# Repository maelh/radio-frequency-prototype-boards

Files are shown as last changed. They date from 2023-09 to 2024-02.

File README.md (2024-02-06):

# RF prototyping boards

When designing radio frequency (RF) circuits, we cannot rely on traditional perfboards or breadboards. Suitable boards need a [ground plane](https://en.wikipedia.org/wiki/Ground_plane#Printed_circuit_boards)  (essential for reducing noise in RF circuits), and should have minimal parasitic capacitances and inductances. Breadboards are especially unsuited, due to their RF circuit altering parasitics (mainly created by the horizontal signal rails, and the vertical power rails).

In the same vein, RF protoboards should support SMT components, which have less parasitic inductance compared to their leaded counterparts.

*This repository presents boards suitable for prototyping RF circuits, [ready to be sent](#fabricating-the-rf-proto-boards) to a PCB manufacturer.*

## Original work (ExpressPCB only)

[MegawattKS](https://www.youtube.com/@MegawattKS) gives an accessible [radio design lecture (YouTube)](https://www.youtube.com/watch?v=r_p7AHsSOdw&list=PL9Ox3wpnB0kqekAyz6blg4YdvoEMoJNJY), with [matching slides](https://ecefiles.org/radio-design-101-slides/), and an accompanying guide detailing [how to prototype RF circuits](https://ecefiles.org/rf-circuit-prototyping/).
It's quite a useful course for getting hands on experience and a non-math heavy intuition, using (comparatively) affordable tools, which are introduced as well: [NanoVNA and TinySA for radio design (YouTube)](https://www.youtube.com/watch?v=B7DFOq9rM_M&list=PL9Ox3wpnB0koBGofotI4xS8R0ct0FeYfv).

When you don't happen to have access to the very expensive RF equipment of a university laboratory, this course is ideal, as it was designed to measure and characterize the built RF circuits with the NanoVNA and the TinySA in mind. (Tools which are widely used in DIY/amateur communities, and accordingly have lots of documentation, tutorial videos, and useful addons available online.)

There is also a more advanced university level course ["Designing and Building Transmitters and Receivers"](https://ecefiles.org/rf-circuits-course-notes/) and its [part list](https://ecefiles.org/wp-content/uploads/2023/01/000b_ECE662_PartsList_F19.pdf).

Finally, MegawattKS kindly provided his [original design for ExpressPCB Plus](/original/RFprotoboard_Rev2_17nov22.rrb), which I used to take measurements of the various footprints and layout dimensions.

## Derived work (KiCad, many PCB manufacturers)

I faithfully redesigned the RF protoboard in KiCad, based on those measurements, to enable fabricating them with pretty much any PCB manufacturer.
The manual conversion was necessary, since the original boards are made for ExpressPCB, which uses a format exclusive to this manufacturer, with no export/import options. 

This resulted in two boards (out of the many variations I tried):

- The [standard version](/RF_ProtoBoard), with all the original dimensions and features being kept.

  <div align="center">
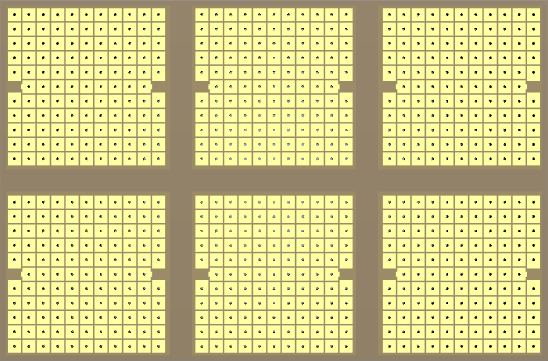
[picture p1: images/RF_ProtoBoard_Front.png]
Front of standard version
    
    <div>Front</div>    
  </div>

  <br/>

  <div align="center">
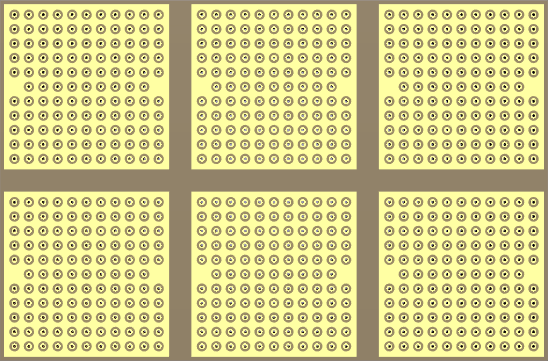
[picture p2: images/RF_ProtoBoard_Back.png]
Back of standard version
    
    <div>Back</div>
  </div>

- The [extended version](/RF_ProtoBoard_Extended), with the following changes compared to the standard version:
  - **added**: mounting holes
  - **added**: screw terminal for power (and pads to solder power wires onto)
  - **extended**: complete 4 pad U.FL connector footprints with silkscreen (for easier alignment)
  - **changed**: ground rings instead of a fully exposed ground plane
    - solder mask only exposes ground rings around the backside of plated through holes; ground rings should form nicer solder joints and hopefully ease solderability to the ground plane

  <br/>
  
  <div align="center">
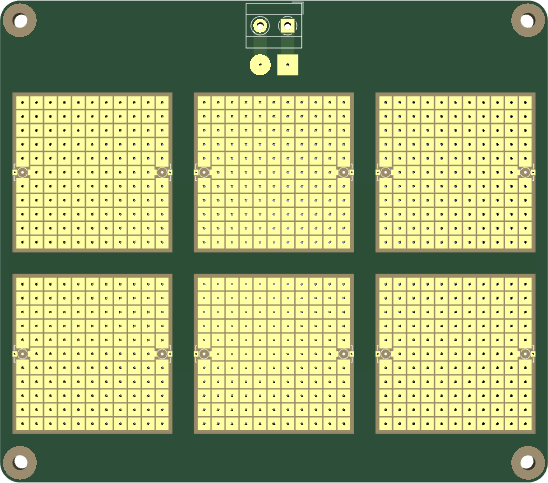
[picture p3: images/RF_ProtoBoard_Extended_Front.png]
Front of extended version
    
    <div>Front</div>    
  </div>

  <br/>

  <div align="center">
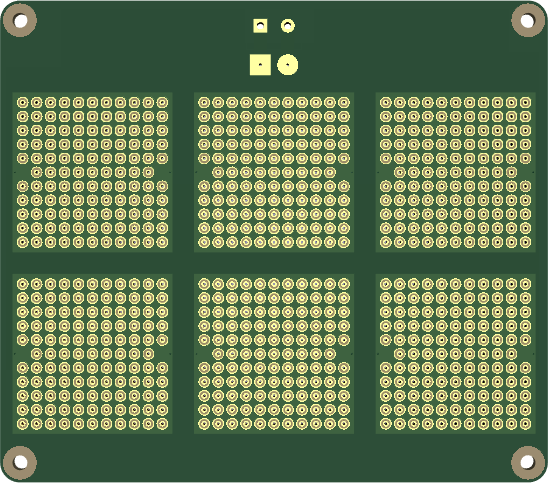
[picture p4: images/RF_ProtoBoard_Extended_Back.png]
Back of extended version
    
    <div>Back</div>
  </div>
  
The screw terminal on the extended version reduces the amount of loose wires going off the board. Now, all the power wires from the 6 sub-modules can be routed to the centrally positioned pair of power pads, which have traces leading to the single central power screw terminal. The power pads on the backside of the board allow to add a decoupling/bulk capacitor.

## Fabricating the RF proto boards

The necessary ZIP files are available in the [fabrication directory](fabrication/), ready to be sent to a PCB manufacturer.
They are tuned for JLCPCB, but you can easily  [adjust the settings](Manufacturing.md#generating-files-manually) as needed when generating the Gerber, drill and map files from within the KiCad projects.

### PCB ordering website options

- *Extended board version:* inform your manufacturer to keep the silkscreen for the U.FL connectors, since it's on the bare PCB substrate (no solder mask underneath). To do so, write a note in the order page remark field: "Keep the silkscreen on the solder mask openings."
- Select "Untented" for "Via Covering".
- *JLCPCB only*: under "Remove Order Number", select "Specify a location". The "JLCJLCJLCJLC" text on the B.Silkscreen layer [specifies the location of the order number](https://jlcpcb.com/help/article/50-How-to-remove-order-number-from-your-PCB).

### Fabrication results, generating files manually, reviewing production files

I received my first extended RF protoboards on October 9, 2023. All tests indicate they are working well -- I made continuity tests with my multimeter -- and they were manufactured to specification regarding silkscreen, drilled hole diameters and correct through hole plating to the ground planes.

More details on how to generate Gerber files manually, my experiences with producing the extended board version, and how to review production files before fabrication begins, can be found under [manufacturing](Manufacturing.md).

## Soldering to the ground plane rings

In the first practical soldering tests, the ground ring design proved to be really easy to use for connecting pads to ground.

Either solder only to the inner ring on the backside to mechanically secure a through hole component to the board, without connecting it to the ground plane, or make a larger solder dome/blob that also covers the outer ground ring to make a ground plane connection.

No special or large sized tip is necessary: I use a 2 mm wide chisel tip, with my soldering station set to about 330°C, using Sn100Ni+ 0.5mm solder wire (see [recommended lead-free solder](NecessaryToolsAndParts.md#recommended-lead-free-solder)).

The only tricky part is to remove solder from the narrow plated through holes, so it is better to plan ahead if you want a throughhole component or a surface mount component on a specific pad.

### Soldering in more detail

Add some solder to the inner ring, then swirl the iron tip around the inner ring and the outer ground ring at the same time and add more solder to make a larger blob/dome. Initially it only bonds to the inner ring, but after a few seconds of swirling, the ground plane ring will also accept the solder. If the joint looks "cold"/crumbly, simply add a little flux and touch up the joint again briefly, so it will create a nice shiny joint.

### Removing a ground connection

Heat up a solder joint and collect excessive solder with the iron's tip, then brush it off on your brass wool cleaner. With less solder it will tend to only cover the inner ring, which means there is no more connection to ground.

Alternatively, use a solder sucker: keep the iron on the rings until the solder melts, then move the iron slightly off the center of the rings, but close enough, so it can keep the solder in a molten state. Then make the (silicone!) tip of the solder sucker touch directly the iron tip, and press the button of the desoldering pump to suck most of the solder away. It works quite reliably, and better than using solder wick.

The solder sucker tip should be made out of silicone, so it doesn't melt when touching the soldering iron.

## Parts and measurement equipment

Aside from measurement equipment, such as the NanoVNA and the TinySA, you will need U.FL connectors, screw terminals, and most importantly, surface mount components, to build RF circuits. See the [list of tools and parts needed](NecessaryToolsAndParts.md).

## Recommended literature

- RF Circuit Design 2nd Edition by Christopher Bowick
  - https://www.amazon.de/RF-Circuit-Design-Christopher-Bowick/dp/0750685182/
- [Ultimate Electronics - Conceptual Foundations of Electrical Engineering](https://ultimateelectronicsbook.com)
- [What is a VNA / Vector Network Analyzer by w2aew](https://www.youtube.com/watch?v=Sb3q8f0NBZc)
- [Basics of Capacitor & Inductor self-resonance, parasitics, etc. - Tutorial - w2aew](https://www.youtube.com/watch?v=vi24SpKYYoQ)
- [Measuring Self-Capacitance and Self-Resonant Frequency SRF of Inductors - KainkaLabs](https://www.youtube.com/watch?v=tjbK4LsOQRk)
- [Impedance Matching with the Smith Chart](https://www.youtube.com/watch?v=_pJ8kh0i2u4)
- https://www.tek.com/en/documents/primer/what-vector-network-analyzer-and-how-does-it-work
- Impedance Measurement Handbook -- A Guide to Measurement Technology and Techniques 
  - https://www.keysight.com/us/en/assets/7018-06840/application-notes/5950-3000.pdf
- https://hexandflex.com/2020/01/11/impedance-matching-with-qucs-studio-and-vna/
- https://www.gunthard-kraus.de/qucsstudio/Tutorial_Qucsstudio_V1-7_M%C3%A4rz%202019.pdf
- https://www.gunthard-kraus.de/fertig_NanoVNA/Deutsch/Nano_H_Deutsch_2020.pdf
- https://www.grund-wissen.de/elektronik/simulationen-mit-qucs.html
- https://electronics.stackexchange.com/questions/677822/s-parameters-calculation-from-vna-file
- https://qucs-help.readthedocs.io/de/qucs-0.0.18/start.html
- https://passive-components.eu/capacitors-losses-esrimpdfq/
- https://www.antenna-theory.com/tutorial/smith/chart.php
- https://groups.io/g/nanovna-users/files/C1-Smith_Chart_Aarhus_CAS_2010_caspers_version_20_September_2010.pdf
- https://www.intmath.com/complex-numbers/9-impedance-phase-angle.php
- https://www.microwaves101.com/encyclopedias/s-parameters
- https://www.baseapp.com/iot/antenna-tuning-for-beginners/
- Fixing calibration issues (see question comments): https://electronics.stackexchange.com/questions/609714/calibrating-a-vna
- Soldering skills and other factors affecting calibration: https://www.antune.net/calibration.html
- https://electronics.stackexchange.com/questions/602730/tuning-an-antenna-using-a-nanovna-smith-chart-and-impedance-readings
- [HP - S-Parameter Techniques for Faster, More Accurate Network Design](http://www.sss-mag.com/pdf/an-95-1.pdf)
- [Testing Inductors at Application Frequencies -- frequency dependent inductance, LCR meters vs VNAs](https://www.coilcraft.com/getmedia/917e2972-9585-4c8f-a94d-9a5b02fdffd9/doc119_testappfreq.pdf)
- [How to Use an LCR Meter: Basic Knowledge](https://www.hioki.com/global/learning/usage/lcr-meters_2.html)
- [Log Mag and Linear Mag (Keysight)](https://rfmw.em.keysight.com/wireless/helpfiles/89600B/WebHelp/subsystems/gui/Content/trace_format_logmag.htm)
- [LiteVNA vs. NanoVNA performance, noise, frenquency range with best accuracy](https://groups.io/g/liteVNA/message/1303)

## Useful software

- http://www.ae6ty.com/Smith_Charts.html
- https://w0qe.com/SimSmith.html
- http://www.physicsbox.com/indexsolveelec2en.html
- https://www.antune.net/
- https://www.atyune.com/

## Related perfboard designs

- https://github.com/electroniceel/protoboard
- https://github.com/jamesmunns/brick-mount
- https://github.com/hyves42/miniboard-protoboard
- https://github.com/mje-nz/protoboard
- https://github.com/AriaSalvatrice/synth-protoboard
- https://hackaday.com/2016/06/16/evaluating-the-unusual-and-innovative-perf-protoboard/
- https://www.busboard.com/SP3T-50x50-G-PTH
  - https://www.amazon.com/SP3T-50X50-G-PTH-SMTpads-3U-Thin-Plated-Ground-50x50mil/dp/B00LLPRNVW

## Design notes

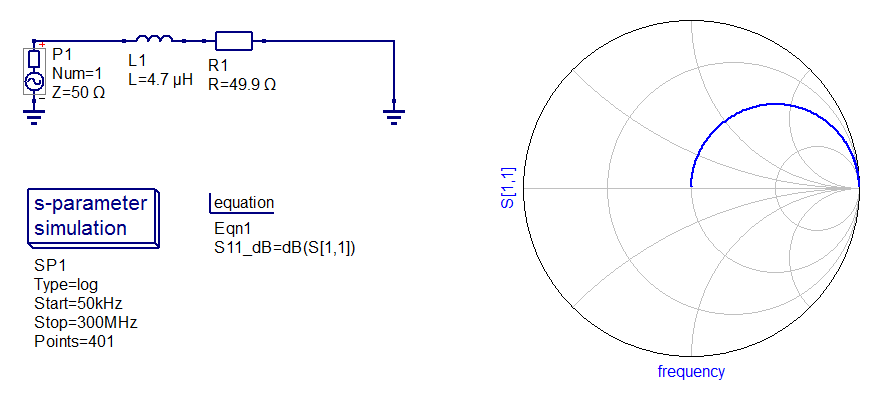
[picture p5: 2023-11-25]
equipment/RF_Demo_Kit/7a - RL series circuit.png

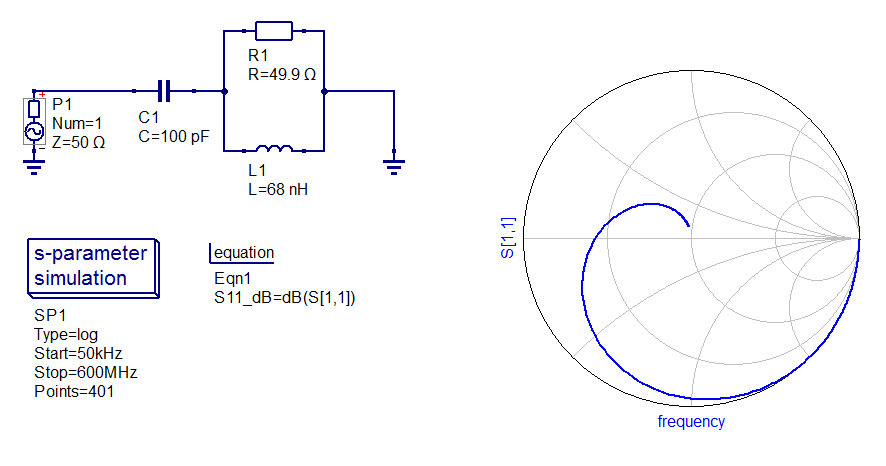
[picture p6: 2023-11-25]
equipment/RF_Demo_Kit/1 - RLC circuit.png

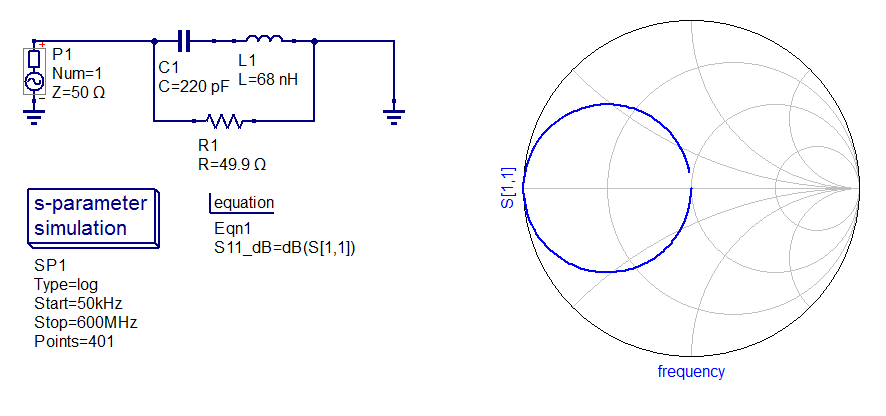
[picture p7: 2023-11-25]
equipment/RF_Demo_Kit/2 - RLC circuit.png

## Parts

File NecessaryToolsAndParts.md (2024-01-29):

# Necessary tools and parts

The RF prototype boards have a 0.1" pin pitch, which means the pad holes are 100 mils (= 2.54 mm) apart from each other. Also, the pads on the boards are separated by 10 mils (= 0.254 mm), so any SMD component that comfortably bridges this gap can be used.

Accordingly, you can *pick SMD components of any of the following sizes*:
  - 0805 (2.0 mm × 1.25 mm)
  - 0603 (1.6 mm × 0.8 mm)
  - 0402 (1.0 mm × 0.5 mm)

Note: SMD sizes are given in [imperial code](https://en.wikipedia.org/wiki/List_of_integrated_circuit_packaging_types#Rectangular_passive_components), not metric code.

Since the SMD parts should make solid connections with the board, the smallest acceptable size is 0402 (1.0 mm × 0.5 mm). Smaller sizes will have their SMD pads reach into the *gap* between two board pads, instead of fully touching the board's pads.

Choose the part size depending on how much of the board pads (and their holes) you want to cover, and for ease of use/soldering.

## Recommended lead-free solder

After trying various lead-free solders, I can recommend Sn100Ni+ as a well flowing solder making nice shiny joints.<br/>
A diameter of 0.5 mm is well suited for SMD components, while still allowing to solder through-hole parts.

The exact solder I use is called `Felder ISO-Core "Ultra-Clear" Sn100Ni+ 0.5mm`.

## SMD component kits and basic parts

- SMD kit with many parts (except inductors)
  - Search terms:
    - Interstellar Electronics SMD Professional Assortment Kit
    - "2900 pcs SMD 1206 0805 0603 Component Assortment, Resistor, Capacitor, Diode, Transistor, OpAmp, IC, Solder, PCB, SMT Soldering Assorted Kit" by Zebulon
    - "SMD SMT Electronic Components Assortment 1206 0805 0603 Resistors Capacitors Diodes Transistors LEDs Potentiometers Opamps ICs Zener PCBs 2900pcs" by Zebulon
  - https://www.amazon.de/gp/product/B08QGD9G7C
- Inductor sample book
  - Search term:
    - SMD Multilayer Ceramic Inductor Kit 0201 0402 0603 0805 1206 Chip Inductance Assorted Kit Sample Book
  - https://www.aliexpress.us/item/1005004268660183.html (pick the "0603 52valuesX25pcs" or the "0805 47valuesX25pcs" option)
- U.FL connectors
  - Search terms:
    - 50PCS IPEX U.FL SMD SMT Solder for PCB Mount Socket Jack Female RF Coaxial Connector
    - IPX U.FL RF Coaxial Plug SMD SMT Soldering Conductor Board Female for Antenna Wireless LAN Equipment Coaxial Cable Pack of 80
  - https://www.amazon.de/gp/product/B0BFQ98MLC
  - https://www.berrybase.de/u.fl-steckverbinder-stecker-50-937-gerade-smd
- Rubber feet with adhesive
- For the *extended* prototype board:
  - Screw terminals with a 5.0 mm pin pitch
    - https://www.amazon.de/gp/product/B0C3HB9HK7
  - M2.5 spacer rods, screws and nuts (nylon, or some other non-conductive material) for the PCB mounting holes
    - https://www.berrybase.de/420-teiliges-nylon-abstandshalter-sortiment-in-kunststoffbox-m2-5-weiss

## Test equipment
- NanoVNA
  - Many different versions, I use [NanoVNA-H4](https://nanovna.com/) (see recommended [vendor list](https://nanovna.com/?page_id=121) to avoid bad clones), MegaWattKS uses [NanoVNA-F](https://deepelec.com/nanovna-f/), both having a 4" screen.
  - Optional microSD card: allows to store / load screenshots, measurements, calibration data, or dump firmware
    - Especially calibration data can only by stored/restored from SD cards, the remaining data can be exchanged over USB
    - [Recommended microSD card](https://groups.io/g/nanovna-users/topic/sd_card_size_and_speed/79473051) is fast, has a size of 8 to 32GiB, is formatted in FAT32, and should support SPI mode
      - *Potentially compatible (if it supports SPI mode)*: microSDHC or microSDHC I (= microSDHC UHS-I)
      - *Not compatible*: microSDHC II (= microSDHC UHS-II), microSDHC III (= microSDHC UHS-III), microSDXC, microSDUC
      - This model works in my NanoVNA-H4 and TinySA Ultra: [SanDisk 32GB (Pack of 2) Ultra microSDHC UHS-I Memory Card (2x32GB) with Adapter](https://www.amazon.com/dp/B08J4HJ98L )
- [TinySA](https://tinysa.org/wiki/pmwiki.php?n=Main.Specification) or [TinySA Ultra](https://tinysa.org/wiki/pmwiki.php?n=TinySA4.Specification)
  - See recommended [vendor list](https://tinysa.org/wiki/pmwiki.php?n=Main.Buying) to avoid bad clones.
  - TinySA Ultra comes with a cheap microSD card, TinySA has none
- **Important:** attenuators and DC blocks
  - For both instruments above you should use attenuators, since the frontends cannot sustain much power.
    - The TinySA will analyze external signals, such as from antennas or signal generators, so attenuators are almost always necessary. The NanoVNA might also need them, when characterizing active circuits, such as amplifiers or mixers. Especially, the TinySA should use an additional DC block, if the internal one is switched off or cannot handle the load.
  - SMA attenuator kit, 6 attenuators of 1dB, 2dB, 3dB, 6dB, 10dB and 20dB, each 2W and 50 Ohm
    - Search term:
      - NooElec SMA Attenuator Kit - 6-piece SMA In-Line attenuator with 2W 50Ohm from 1dB to 42dB in increments of 1dB.
    - https://www.amazon.de/dp/B07YYMT65T?language=en_GB  
  - One or two SMA DC blocks, 6 GHz and 50 Ohm
    - Search term:
      - NooElec SMA DC Block - High Quality Inline 50ohm 50kHz 8GHz Terminal Blocks DC
    - https://www.amazon.de/dp/B07YYLHJKS?language=en_GB
- SMA female to SMA male coaxial extension cable
  - Used to create a *simple RF probe* with 40 db attenuation, as described in https://youtu.be/B7DFOq9rM_M?t=858
    - A 4.7 kOhm resistor is stuck into the female SMA connector as a signal pin, and as a ground lead, a piece of wire is wraped around the same female SMA connector, then secured with a nut
    - See also: [A wideband 1:21 DIY 1 kΩ oscilloscope probe](http://jahonen.kapsi.fi/Electronics/DIY%201k%20probe/)
  - Search terms:
    - 6.5ft (2 m) Low-Loss Coaxial Extension Cable RG58 (50 Ohm) SMA Male to SMA Female
    - RG174 SMA Coaxial Cable SMA Male to SMA Female RF Coaxial Cable 6.6 Feet (2 m) + 3 Pieces SMA Adapter Set Low Loss Extension Cable
    - SMA Extension Cable RG58 6.6ft (2M) SMA Male to SMA Female Coaxial Cable Low Loss RF Coaxial Cable
  - https://www.amazon.de/dp/B0C1BFXMWD
  - https://www.amazon.de/dp/B0995QWSS5
- U.FL to SMA Male Coaxial RG178 Low Loss Cable
  - Used to connect the U.FL inputs/outputs of the RF protoboards to oscilloscopes/signal generators/vector network analyzers/spectrum analyzers
  - Search term:
    - U.FL to SMA Coaxial Cable SMA Male to UFL IPX IPEX Coaxial Cable RG178 12 Inch (30 cm) Pack of 5
  - https://www.amazon.de/dp/B0C1BFXMWD
- Stylus pen for touchscreen (of NanoVNA/TinySA)
  - The TinySA user group has a discussion about [possible stylus options](https://groups.io/g/tinysa/topic/80388765?p=Created%2C%2C%2C20%2C1%2C0%2C0)
 
### Basic addons
- "RF Demo Kit" with U.FL sockets for NanoVNA
  - Has symbolic Smith charts, components for SOLT calibration, example filters, attenuators, resistors, capacitors, inductors, and combinations of the last three basic components, all accessible via U.FL connectors
    - [RF demo kit quickstart guide](https://www.deepelec.com/files/Rf_Demo_Kit_Quick_start_guide_v2.0.pdf)
    - [Practical usage guide](https://groups.io/g/nanovna-users/wiki/16592)
      - Do **not** use a **screw driver** to remove U.FL cables (it will apply unequal force and bend/damage the sockets/plugs). Instead use SMD tweezers like a lever, positioned below the U.FL cable's plug, such that you apply an equal force from both sides (with the two "prongs" of the tweezer) and by finding the center pivot point of the plug.
  - [Discussion about some inaccurate graphs](https://groups.io/g/nanovna-users/topic/rf_demo_kit_testing_tutorial/65778338) due to inductor quality issues
  - Original idea: [VNA Sandbox](https://www.megiq.com/products/vna-sandbox)
    - [RF Demo Kit tutorial presentation and VNA Sandbox origin](https://groups.io/g/nanovna-users/topic/65778338)
  - Search terms:
    - "RF Demo Kit for NanoVNA-F" by [Deepelec](https://deepelec.com/rf-demo-kit/) / SYSJOINT
    - RF Demo Kit for F RF Tester Board HAM Filter Attenuator 
  - https://www.amazon.de/dp/B0BRCL158V
- 2x "NanoVNA Testboard Kit" with SMA connectors
  - Has female headers to insert and measure components, and SMD pads to build and measure tiny circuits, such as simple filters
  - [Documentation](https://www.sdr-kits.net/documents/Testboard_kit.pdf)
- stethoscope camera with microphone (or stethoscope  microphone alone)

### Advanced add-ons
- VNA Test Boards
  - https://www.youtube.com/watch?v=29YcNXSB9KM
- RF probe
  - https://emcesd.com/1ghzprob.htm
- https://www.ph2lb.nl/blog/index.php?page=xtal-adapter-for-nanovna
- https://www.ph2lb.nl/blog/index.php?page=qrp-labs-filter-adapter-for-nanovna
- https://www.ph2lb.nl/blog/index.php?page=rfsampler
- Mostly for the manual (but the NanoVNA Testboard Kit (see above) is better):
  - https://www.ph2lb.nl/blog/index.php?page=component-measuring-adapter-for-nanovna

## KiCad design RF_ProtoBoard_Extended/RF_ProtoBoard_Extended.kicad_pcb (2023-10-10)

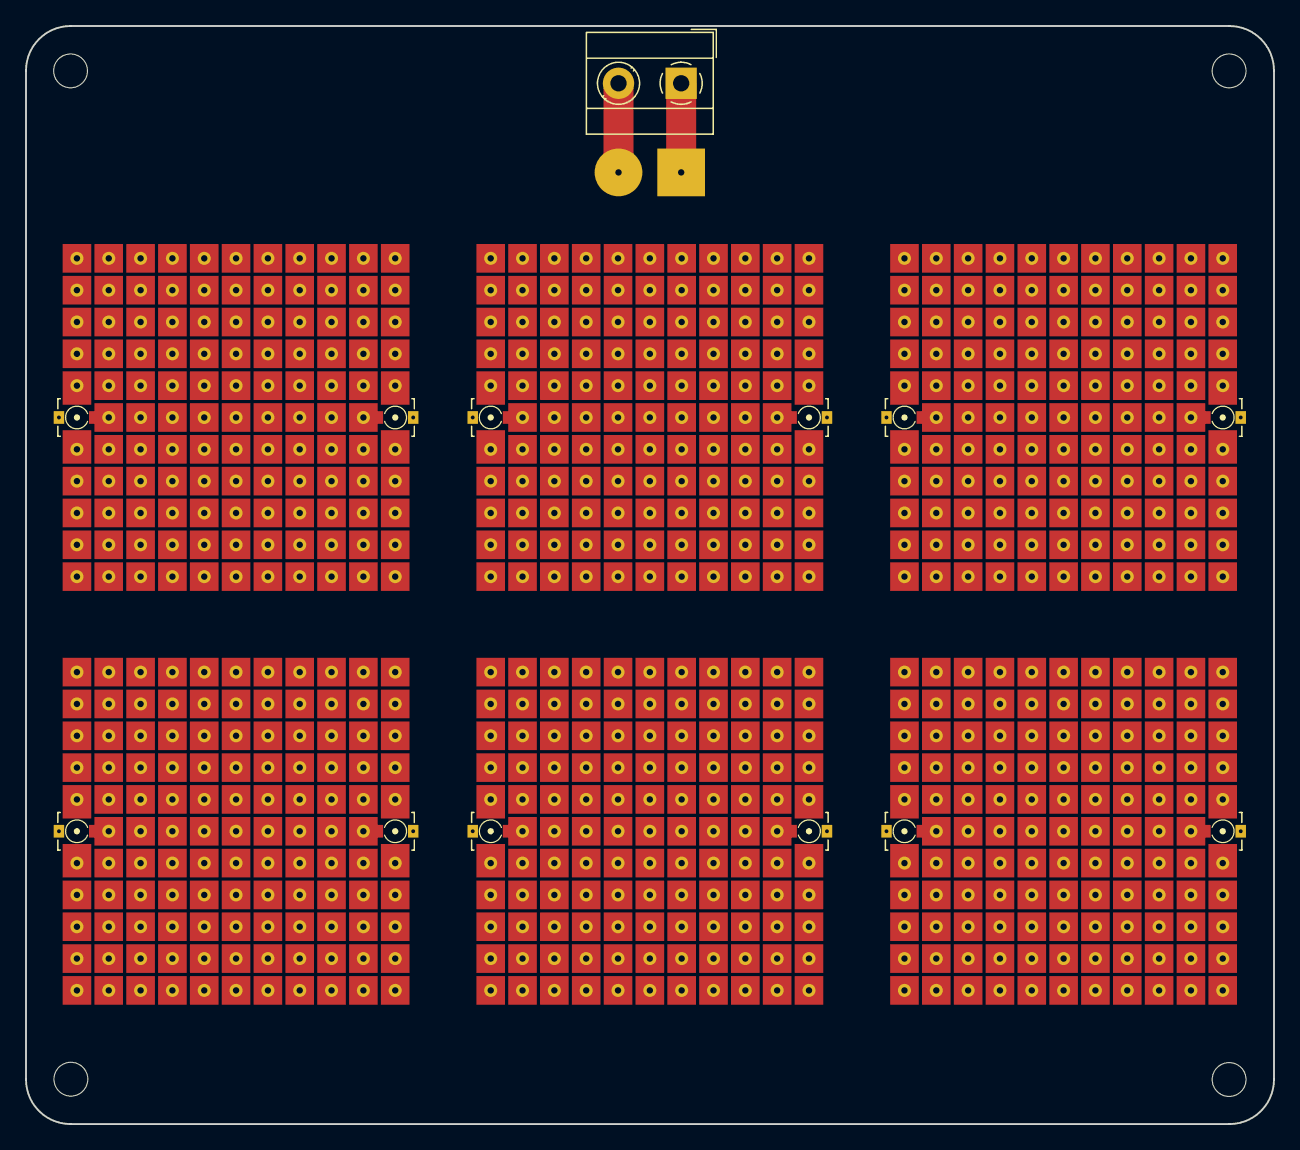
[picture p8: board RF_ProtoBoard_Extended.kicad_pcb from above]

Board: 2 copper layers, 99.6 x 87.6 mm, 12 parts (0 on the bottom side), 8 nets.

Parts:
A1, A2, A3, A4, A5, A6: GndRing_RF_ProtoBoard_Module
H1, H2, H3, H4: MountingHole; MountingHole_2.7mm_M2.5_Clearance_1.7mm
J1: Screw_Terminal_01x02; TerminalBlock_MetzConnect_Type055_RT01502HDWU_1x02_P5.00mm_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
J2: Conn_VPlus_Gnd; VPlus_Gnd_Pads

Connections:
/Gnd: J1.1, J2.1
/V+: J1.2, J2.2
GND1: A1.0 (Pin_Gnd), A1.6a, A1.6k
GND2: A2.0 (Pin_Gnd), A2.6a, A2.6k
GND3: A3.0 (Pin_Gnd), A3.6a, A3.6k
GND4: A4.0 (Pin_Gnd), A4.6a, A4.6k
GND5: A5.0 (Pin_Gnd), A5.6a, A5.6k
GND6: A6.0 (Pin_Gnd), A6.6a, A6.6k

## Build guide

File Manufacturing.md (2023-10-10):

# Fabricating the RF proto boards

The necessary ZIP files are available in the [fabrication directory](fabrication/), ready to be sent to a PCB manufacturer.
They are tuned for JLCPCB, but you can easily adjust the settings as needed when generating the Gerber, drill and map files from within the KiCad projects (see [below](#generating-files-manually)).

## PCB ordering website options
- *Extended board version:* inform your manufacturer to keep the silkscreen for the U.FL connectors, since it's on the bare PCB substrate (no solder mask underneath). To do so, write a note in the order page remark field: "Keep the silkscreen on the solder mask openings."
- Select "Untented" for "Via Covering".
- *JLCPCB only*: under "Remove Order Number", select "Specify a location". The "JLCJLCJLCJLC" text on the B.Silkscreen layer [specifies the location of the order number](https://jlcpcb.com/help/article/50-How-to-remove-order-number-from-your-PCB).

## Generating files manually

The project is set up to work correctly with JLCPCB, with all the necessary layers selected and the options properly set.

- Standard board version:
  - Make sure "Do not tent vias" is enabled.
  - "JLCJLCJLCJLC" text on the B.Silkscreen layer:
    - For JLCPCB: do **not** enable "Subtract soldermask from silkscreen", otherwise the text will be clipped, and the ordering number will be placed at a random location.
    - For others: hide the text, as it will be unnecessary clutter.

- Extended board version:
  - Make sure "Do not tent vias" is enabled.
  - "JLCJLCJLCJLC" text on the B.Silkscreen layer:
    - For JLCPCB: keep the text visible, so the ordering number is not placed at a random location.
    - For others: hide the text, as it will be unnecessary clutter.
  - Do **not** enable "Subtract soldermask from silkscreen", unless the silkscreen for the U.FL connectors creates issues, because it is printed on the bare PCB substrate. If you keep the U.FL silkscreen, make sure to let the manufacturer know that the silkscreen on the bare PCB substrate is intentional. To do so, write a note in the order page remark field: "Keep the silkscreen on the solder mask openings."

Default plot settings (menu`File|Fabrications Output|Gerbers (.gbr)...`) for standard and extended board versions:

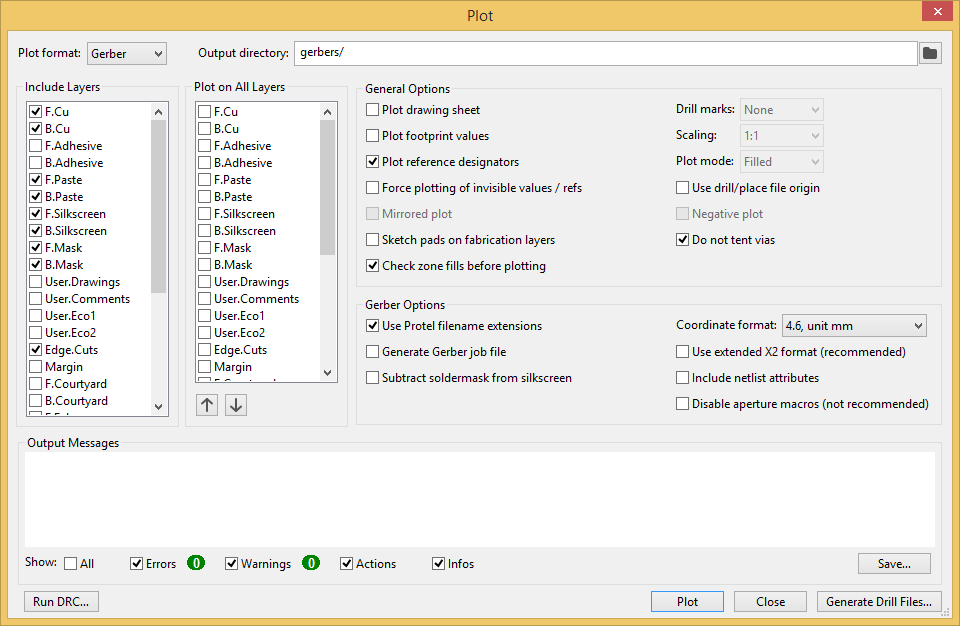
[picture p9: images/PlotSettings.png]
KiCad 7 plot settings


Now, generate the Gerber, the drill, and the map files. The results will be in the gerbers/ sub-directory. Put all the generated files in gerbers/ into a ZIP file, and upload them to your manufacturer.

See also:
  - [How to generate Gerber and Drill files in KiCad 7 (JLCPCB)](https://jlcpcb.com/help/article/362-how-to-generate-gerber-and-drill-files-in-kicad-7)
  - [How to Generate Gerber and Drill Files in KiCad 7.0 (PCBWay)](https://www.pcbway.com/helpcenter/technical_support/How_to_Generate_Gerber_and_Drill_Files_in_KiCad_7_0.html)

## Experience with submitting designs to JLCPCB

I fabricated the extended board version at JLCPCB. For my first (and so far only) order, I enabled "Confirm Production file", which turned out to be a good idea. Initially, they reduced the solder mask openings on the back side, which effectively removed the ground ring. Also, the silkscreen for the U.FL connectors on the front was removed and then, when communicating to readd them, they were clipped.

I suspect the wording in the remark field on the order page was the issue, so I updated it in the README to match their wordings more closely: "Keep the silkscreen on the solder mask openings." (same note is mentioned in ordering instructions above). The clipping was possibly due to the closeness to the SMD pads on the front. I was reviewing their changes directly and sending pictures comparing their version and my desired version, with arrows pointing out the differences too clarify, but maybe a note "Keep silkscreen close to copper pads unchanged." could help.

Similarily, for the reduced solder mask openings on the back side, a note saying "Solder mask openings on back side of PTH is intentionally covering the adjacent ground plane." However I suspect such a statement will not work, as in my experiece images worked best. Ideally, you could point that out in something like the Fab layer, adding arrows to say the crossing of two copper regions (ring around PTH and ground plane) is intentional.

In the production files (if you chose to review them), diameters of PTHs will be enlarged, but that is to account for the narrowing of the holes when copper plating them, and is normal. Otherwise, I saw minor dimension changes of pads, but its mostly cosmetic: the outer ground pads for the U.FL connectors was enlarged and moved a bit and is now protruding from the rectangular frame. I mostly would like to know why it happened -- possibly to account for the via size, but the change was minimal --, so I can account for it in other boards/situations, where it might be relevant. But it was not worth the effort to keep delaying production.

In general, watch out for some changes manufacturers will automatically apply to your design: [relevant instructions when ordering at JLCPCB](https://jlcpcb.com/help/article/14-Instructions-for-ordering). Somewhat related: [How to Order Boards with Solder Mask Defined Pads (JLCPCB)](https://jlcpcb.com/help/article/84-How-to-Order-Boards-with-Solder-Mask-Defined-Pads).

### DFM (Design for manufacturability) analysis / checks

If you selected the "Confirm Production file" option, you will receive a RAR/ZIP file with several folders.
The [`ok` folder contains the production files](https://www.libreservo.com/en/articulo/how-check-jlcpcb-production-files) used by the manufacturer for fabrication, and your original design is found in the `YG` folder.

To review production files received from fabs such as PCBpartner or JLCPCB, you can use [iPCB-DFM](https://www.pcbpartner.com/iPCB-DFM). Given the screenshots I received, it seems to be the same software that JLCPCB uses for reviewing. In iPCB-DFM choose `File|Open odb` and select the TGZ file in the `ok` folder.

You can also simply do a manual visual compare using KiCad Gerber viewer, to see what changes the fab made. In that case, open all the Gerber files, that have simple names (the names are essentially Protel file extensions). For a two layer design, like the protoboards here, the relevant files are: bl, bo, bs, drl, ko, tl, to, ts.

If you want to check your design before submitting it to a manufacturer, you can use [FreeDFM](https://www.my4pcb.com/net35/FreeDFMNet/FreeDFMHome.aspx).

### Manufacturing process

If you are curious, here is also a description of [how boards are fabricated step by step in a factory](https://www.digikey.com/en/maker/blogs/2018/how-is-a-pcb-manufactured).

### Fabrication results

I received my first extended RF protoboards on October 9, 2023. All tests indicate they are working well -- I made continuity tests with my multimeter -- and they were manufactured to specification regarding silkscreen, drilled hole diameters and correct through hole plating to the ground planes.

I haven't sent the standard design to a PCB manufacturer yet. Let me know if there are any issues in manufacturability and what instructions you followed to be successful.

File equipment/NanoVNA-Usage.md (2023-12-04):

# Using the NanoVNA

## Calibration

The official manual of the NanoVNA has a section on [how to calibrate the NanoVNA](https://nanovna.com/?page_id=2). The following will only focus on information missing from the manual.

Before starting calibration, reset all using the menu entry `CALIBRATE>RESET`.

### Calibration status

On the left side of the screen there are 7 symbols, stacked upon each other, that indicate what was calibrated:

```
C<n>
D
R
S
T
X
Pa
```

In general, `<n>` is a placeholder for a digit from 0 to 9.

`<n>` in `C<n>` specifies the storage index of the currently used calibration data. `C0` is the calibration data that is loaded by default on start.

`Pa` can also be `P<n>`, where `<n>` is 2, 4, 6, or 8. That is, aside from `Pa`, possible symbols are `P2`, `P4`, `P6`, `P8`.

If one (or more) of the 7 vertical symbols are missing, calibration for that part is not present/was reset/not loaded. If an indicator is shown in lower case or another color, the currently loaded calibration is only of limited validity, since some parameters the calibration depends upon (such as stimulus settings) were changed after calibration.

Examples:
  - `c0` means calibration data from storage index 0 was loaded, which was created with a frequency sweep span of 50kHz to 900MHz, which is different from the currently set sweep span of 50kHz to 600MHz.
  - `Pa` is shown in red, because calibration was done with output power level set to 2mA, i.e., `P2` and not auto output power level `Pa`.

#### Meaning of each symbol

- `O` -- `open` calibration data for port 1 is present
- `S` -- `short` calibration data for port 1 is present
- `D` -- `load` calibration data for port 1 is present
- `X` -- `isolation` calibration data for port 1 and 2 is present
- `t` -- `through` calibration data for port 1 and 2 is present

jjj

- `C<n>` -- currently selected calibration data, where `<n>` is the storage index
  - `C*` is calibration data stored RAM only, and therefore has not storage index
  - `C0` is the default calibration data, loaded upon start of the NanoVNA.

- `R` -- `open` calibration data for port 1 is present

- `T` -- `through` calibration data for port 1 and 2 is present

- `Pa` or `P<n>` -- currently selected output power level (of clock generator)
  - `Pa` is short for `Power Auto`, i.e., output power level depends on frequency (and is automatically chosen).
  - `P<n>` means fixed output power level, i.e., same power level of value `<n>` for all frequencies.
    - Possible values are `P2`, `P4`, `P6`, or `P8`, which mean 2mA, 4mA, 6mA, or 8mA, respectively.
  - `Pa`/`P<n>` indicator shown in `red`, if it doesn't match the power level used during calibration.
  - See the menu entry `CALIBRATE>POWER AUTO` or `CALIBRATE>POWER <n>mA`.

### Tips

The measurement accuracy and observable artifacts on graphs can vary depending on a few settings. If you change them, be sure to save the config, and then calibrate your NanoVNA again.

- Select the right `mode`/clock generator chip to reduce artifacts
  - Older versions of the NanoVNA use Si5351 chips, while newer ones use MS5351 chips. To identify which chip your model has, look for an `_MS` suffix on the hardware version label on the [back of the NanoVNA](https://groups.io/g/nanovna-users/message/31631). For example, `HW version: 4.3_MS` indicates a MS5351 model.
  - After a firmware update, several config settings might have been changed or reset to defaults (e.g., the Si5351 mode is the default, which is only valid for older NanoVNAs). A wrong setting will result in excessive artifacts/unsteadiness in the graphs. To solve this issue, see the menu entry `CONFIG>EXPERT SETTINGS>MORE>MODE` and select the right model.

- Adjust `threshold` if you see spurs around or below 300MHz
  - Officially the clock generator chips/frequency synthesizer chips are only specified up to 200MHz, but often work up to 300MHz. In case they do not, the threshold has to be adjusted until spurs are reduced. See the menu entry `CONFIG>EXPERT SETTINGS>THRESHOLD` and experiment with the value.
- Adjust `IF bandwidth` when you see unsteady graphs
  - Firmware updates can change the IF bandwidth from 1000Hz to 4000Hz, which can cause less accuracy/unsteady graphs. See the menu entry `DISPLAY>IF BANDWIDTH` to change the value back to 1000Hz.
- Increase `sweep points` for improved accuracy
  - More sweep points will increase the resolution of your graphs, since more samples are taken, i.e., the steps between two sampled frequencies are smaller. See the menu entry `STIMULUS>SWEEP POINTS`. It will also slow down the refresh rate of the screen, so it's a tradeoff.
- Firmware issues creating measurement instabilities
  - https://groups.io/g/nanovna-users/message/29530
## Measuring

If you have the RF Demo Kit mentioned in [NecessaryToolsAndParts](NecessaryToolsAndParts.md), you can test your NanoVNA and see if it creates valid results.

### RF demo kit

I simulated many of the circuits on the RF demo kit, to see what curves to really expect on the Smith Charts, not just the simplified ones shown on the PCB or documentation. This also gave me the opportunity to collect all data in one place: component values, frequency sweep range, circuit diagram, corresponding Smith Chart.

## Testing if your NanoVNA is in order

https://groups.io/g/nanovna-users/topic/testing_if_a_nanovna_is_good/102706813

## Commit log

2023-09-16 Add extended version
    [RF_ProtoBoard_Extended.kicad_pcb, RF_ProtoBoard_Extended.kicad_sch]
2023-09-16 Allow silkscreen on bare PCB
2023-09-17 Excluded from BOM, disable allow_soldermask_bridges
    [RF_ProtoBoard_Extended.kicad_sch]
2023-09-17 Hide references from silkscreen
    [RF_ProtoBoard_Extended.kicad_pcb]
2023-09-17 Add courtyard
    [RF_ProtoBoard_Extended.kicad_pcb]
2023-09-17 Remove some footprints from POS file
    [RF_ProtoBoard_Extended.kicad_pcb]
2023-09-17 No tented vias
    [RF_ProtoBoard_Extended.kicad_pcb]
2023-09-17 Fix courtyard and solder_mask_bridges warning
    [RF_ProtoBoard.kicad_pcb]
2023-09-17 exclude from bom and pos files
2023-09-17 Adapt plot settings
    [RF_ProtoBoard.kicad_pcb]
2023-09-18 add "JLCJLCJLCJLC" to back silkscreen layer, to specify location of JLCPCB order number
    [RF_ProtoBoard.kicad_pcb, RF_ProtoBoard_Extended.kicad_pcb]
2023-09-19 Update gerber export options
    [RF_ProtoBoard.kicad_pcb, RF_ProtoBoard_Extended.kicad_pcb]
2023-09-19 Update gerbers
2023-09-19 gerber -> gerbers
    [RF_ProtoBoard.kicad_pcb, RF_ProtoBoard_Extended.kicad_pcb]
2023-09-19 Update plot settings
    [RF_ProtoBoard.kicad_pcb, RF_ProtoBoard_Extended.kicad_pcb]
2023-10-10 Add version number to the backside silkscreen
    [RF_ProtoBoard_Extended.kicad_pcb]
2023-10-10 Set PCB's revision variable, and automatically update back silkscreen accordingly
    [RF_ProtoBoard_Extended.kicad_pcb]
2023-10-10 Add ProductNumberPlaceholder text variable; makes it easier to change placeholder text (or entirely remove it) depending on manufacturer
    [RF_ProtoBoard_Extended.kicad_pcb]
2023-10-10 Normalize line endings
    [RF_ProtoBoard_Extended.kicad_pcb]
2023-11-25 Add RF demo kit instructions
    [1 - RLC circuit.sch, 10 - Single inductance.sch, 2 - RLC circuit.sch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]
